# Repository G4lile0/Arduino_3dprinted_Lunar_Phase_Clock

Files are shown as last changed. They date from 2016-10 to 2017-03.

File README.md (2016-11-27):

# Arduino_3dprinted_Lunar_Phase_Clock

<p><a rel="nofollow" href="https://www.youtube.com/watch?v=8Un9RubtGH0">https://www.youtube.com/watch?v=8Un9RubtGH0</a></p>
<h3>3D printed Lunar Phase Clock, designed by G4lile0 2016</h3>
<p><strong>Since there isn't a SuperMoon everyday, make one for your bedside table!!</strong></p>
<p>If you don't know what to print with your 3D printer, here you have an easy project.<br>
Build a 3D printed Lunar Phase Clock for your desk.</p>
<p>Features: (check the video)</p>
<ul>
<li>Open Tools (Ubuntu / FreeCAD / Arduino)</li>
<li>Open Source / Hardware</li>
<li>Cheap HW (Arduino, cheap LCD..) </li>
<li>Only 79 grams of filament.</li>
<li>Precise Lunar Phase Simulation</li>
<li>Detailed 3D printed Lunar model<br>
by Dexter_New_Materials (<a rel="nofollow" href="http://www.thingiverse.com/thing:1014620">http://www.thingiverse.com/thing:1014620</a>)</li>
<li>Alarm  </li>
<li>Wake-light alarm mode</li>
<li>Date </li>
<li>Thermometer</li>
<li>Hygrometer</li>
<li>Lamp mode</li>
<li>Moon FX modes (Relax, Party... )</li>
<li>Bright control</li>
<li>Adjustable tilt</li>
</ul>
<p>Parts List:</p>
<ul>
<li>Arduino compatible Nano (Atmel ATmega328)</li>
<li>0,96'' OLED 128x64 with SSD1306 chip</li>
<li>APA102C led strip  (18 leds)</li>
<li>Tiny RTC (DS1307 real time clock + 24C32 EEPROM)</li>
<li>DTH11 </li>
<li>Buzzer </li>
<li>3 Push Buttons</li>
</ul>
<p><br>
</p>
<h3>Reloj con fase Lunar impreso en 3D diseñado por G4lile0</h3>
<p><strong>Como no todos los días hay una SuperLuna ¡¡fabrícate una para la mesilla de noche!!</strong></p>
<p>Si no sabes que imprimir con tu impresora en 3d, aquí tienes un reloj con fase lunar para tu mesa. </p>
<ul>
<li>Creado solo con herramientas libres (Ubuntu / Freecad / Arduino) </li>
<li>Open Source / Hardware</li>
<li>Electrónica económica (Arduino, LCD)</li>
<li>Tan solo 79 gramos de filamento</li>
<li>Precisa simulacion de la fase lunar</li>
<li>Modelo detallado de la luna<br>
by Dexter_New_Materials (<a rel="nofollow" href="http://www.thingiverse.com/thing:1014620">http://www.thingiverse.com/thing:1014620</a>)</li>
<li>Reloj analogico y digital</li>
<li>Alarma con simulación de amananecer</li>
<li>Alarma</li>
<li>Fecha</li>
<li>Termometro</li>
<li>Monitor de Humedad</li>
<li>Lampara</li>
<li>Modos Demo (Disco /Relax...)</li>
<li>Control de brillo</li>
<li>Inclinación regulable</li>
</ul>
<p>Componentes:</p>
<ul>
<li>Arduino compatible Nano (Atmel ATmega328)</li>
<li>0,96'' OLED 128x64 with SSD1306 chip</li>
<li>APA102C led strip  (18 leds)</li>
<li>Tiny RTC (DS1307 real time clock + 24C32 EEPROM)</li>
<li>DTH11 </li>
<li>Buzzer </li>
<li>3 botones.</li>
</ul>

##Circuito // Circuit
<br>
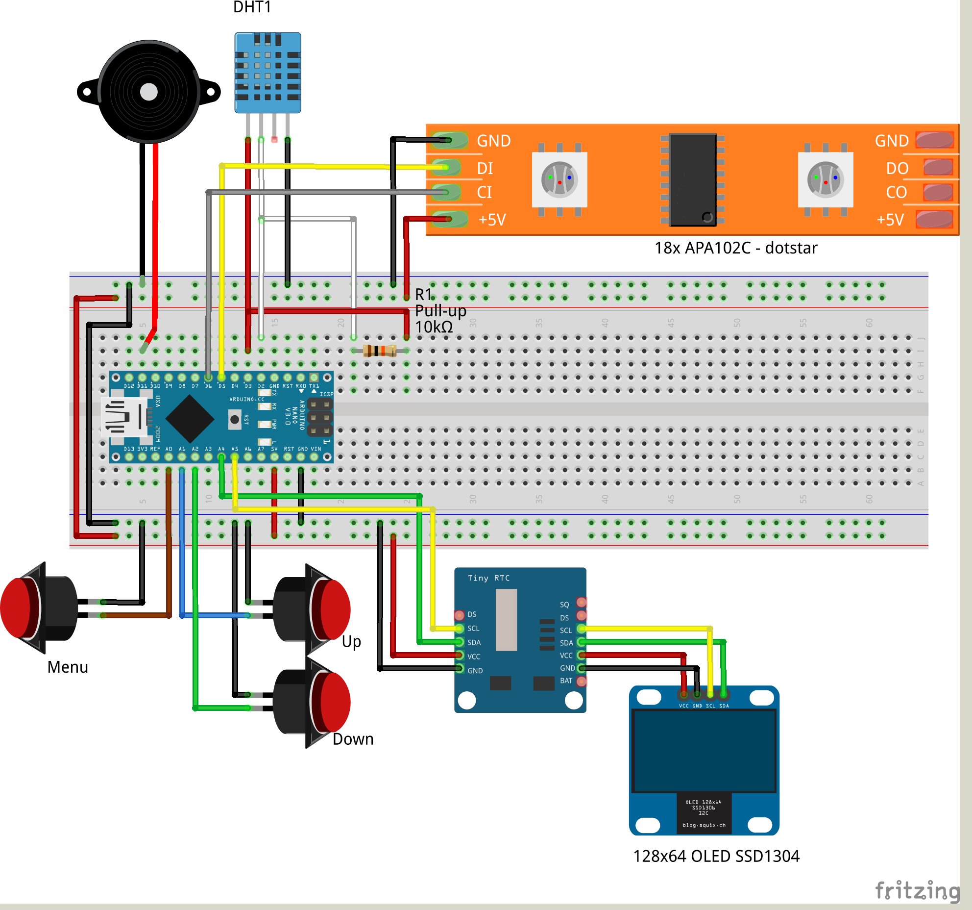
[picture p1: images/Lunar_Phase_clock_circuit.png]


##License



All these products are released under [Creative Commons Attribution-ShareAlike 4.0 International License](http:creativecommons.org/licenses/by-sa/4.0/).
<br>
Todos estos productos están liberados mediante [Creative Commons Attribution-ShareAlike 4.0 International License](http:creativecommons.org/licenses/by-sa/4.0/).

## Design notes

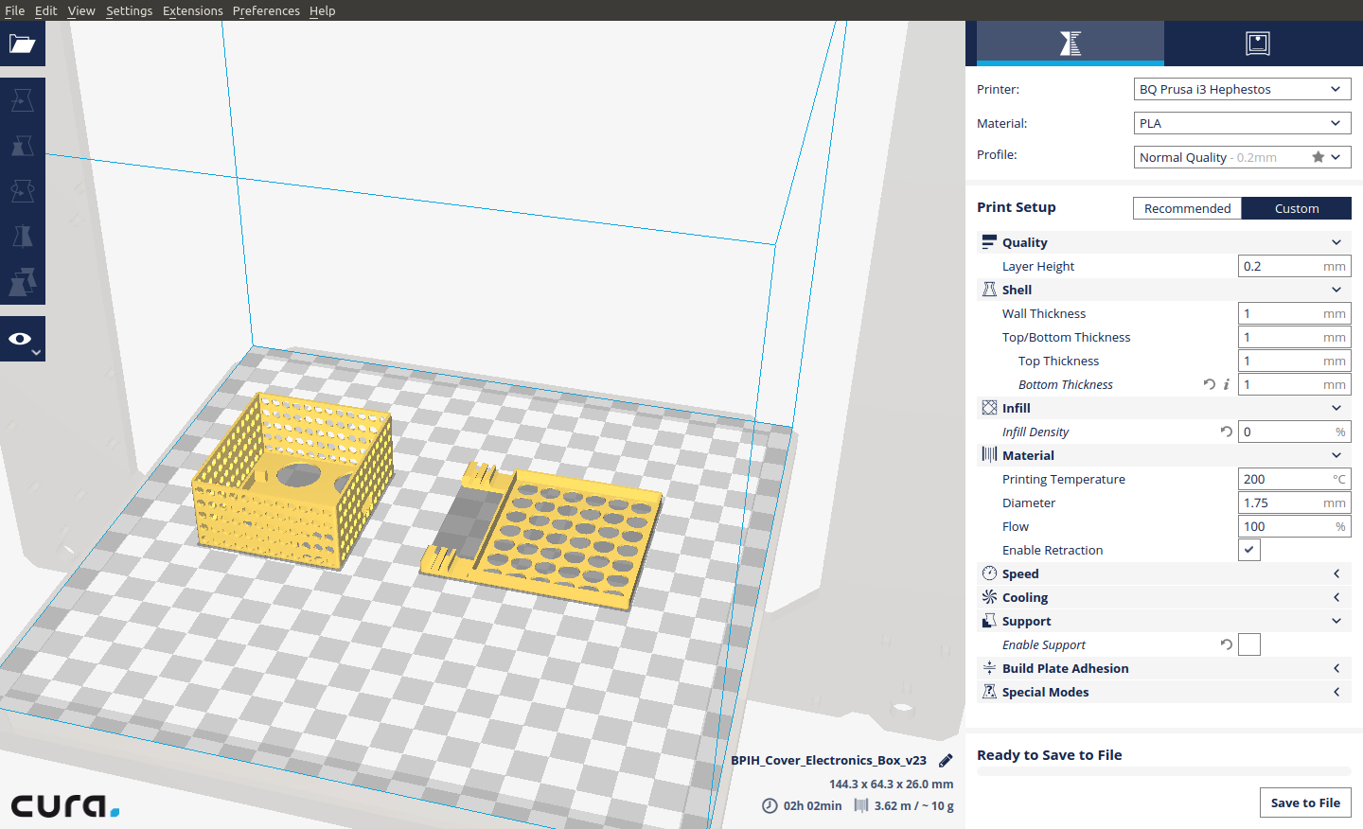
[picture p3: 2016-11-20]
images/electronic_box.png

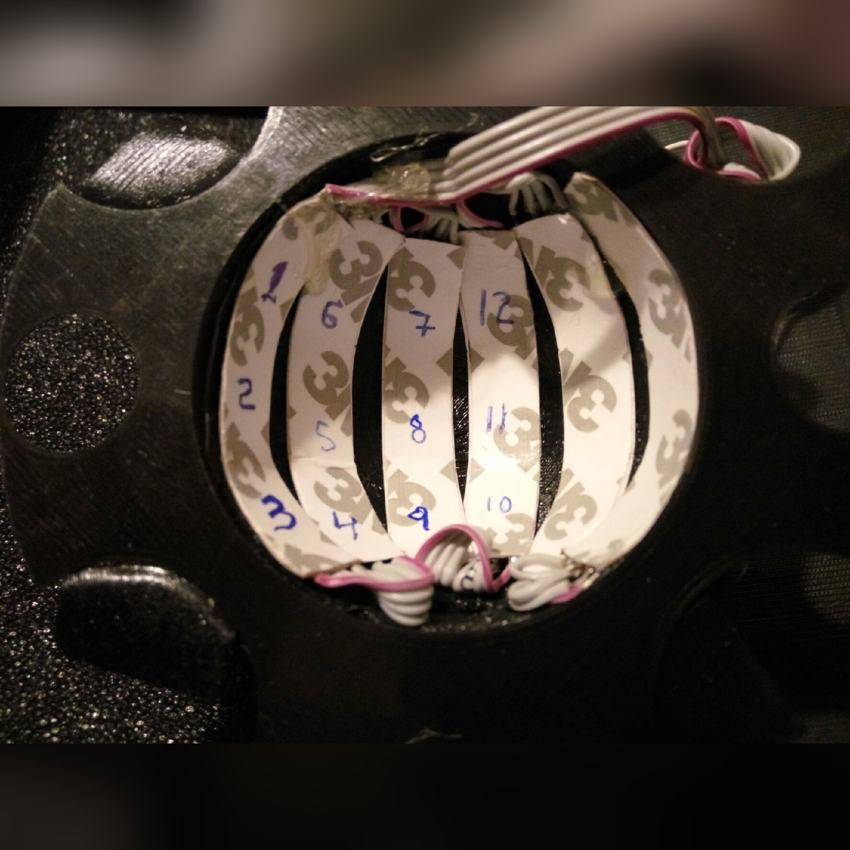
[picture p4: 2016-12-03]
images/led_support_photo.jpg

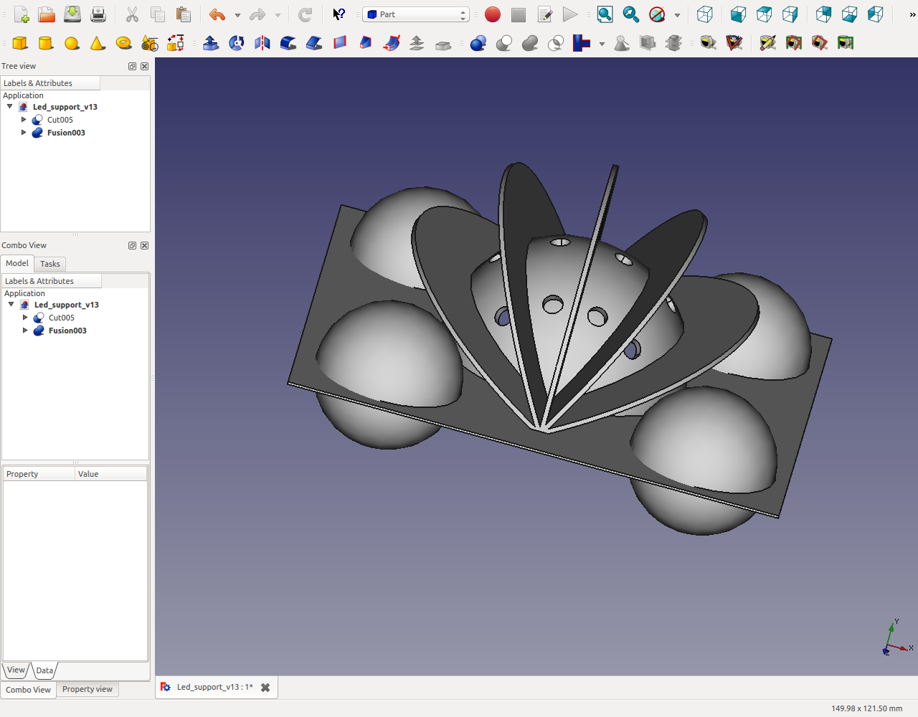
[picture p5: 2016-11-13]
images/Captura de pantalla de 2016-09-18 00-10-19.png

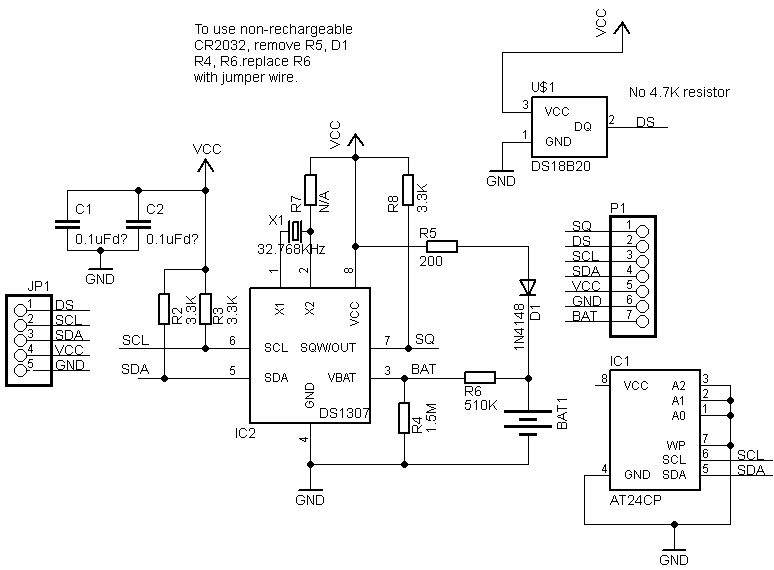
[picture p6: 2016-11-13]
images/TinyRTC.jpg

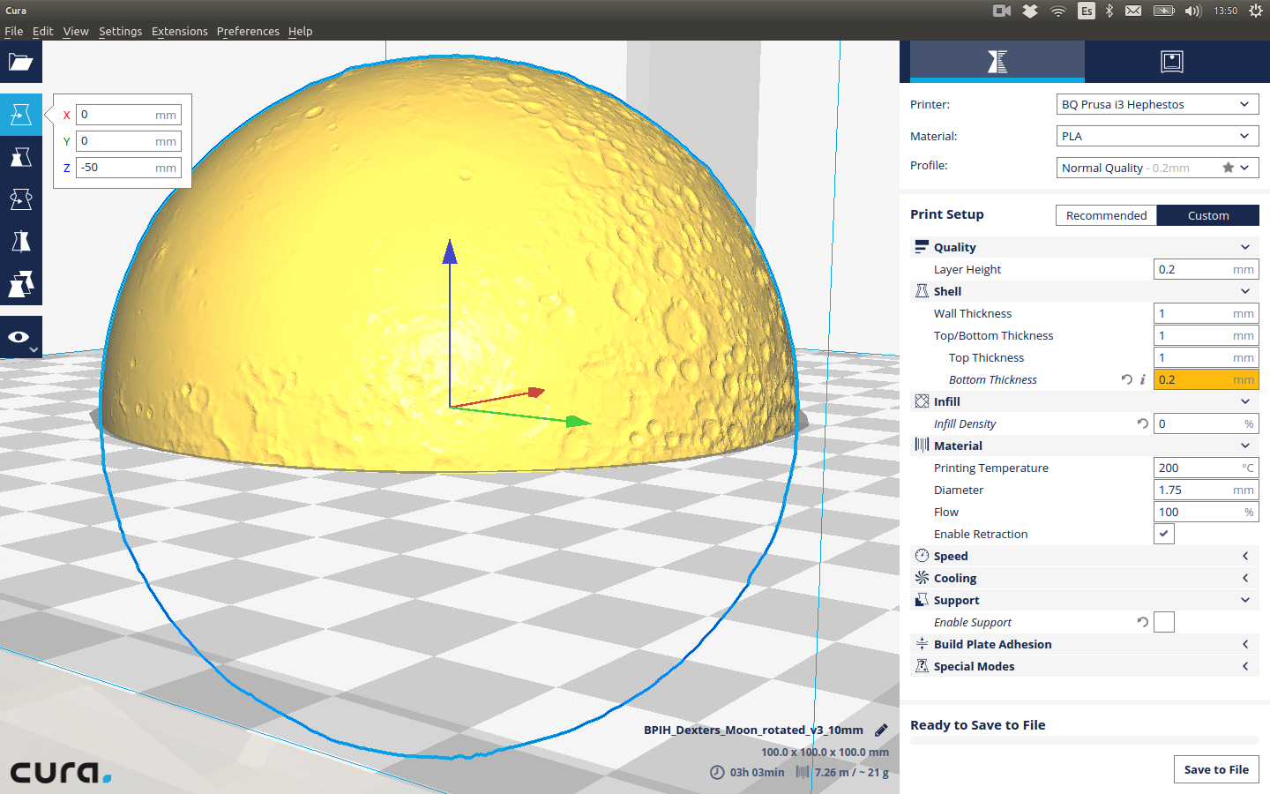
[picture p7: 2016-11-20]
images/cura_moon.png

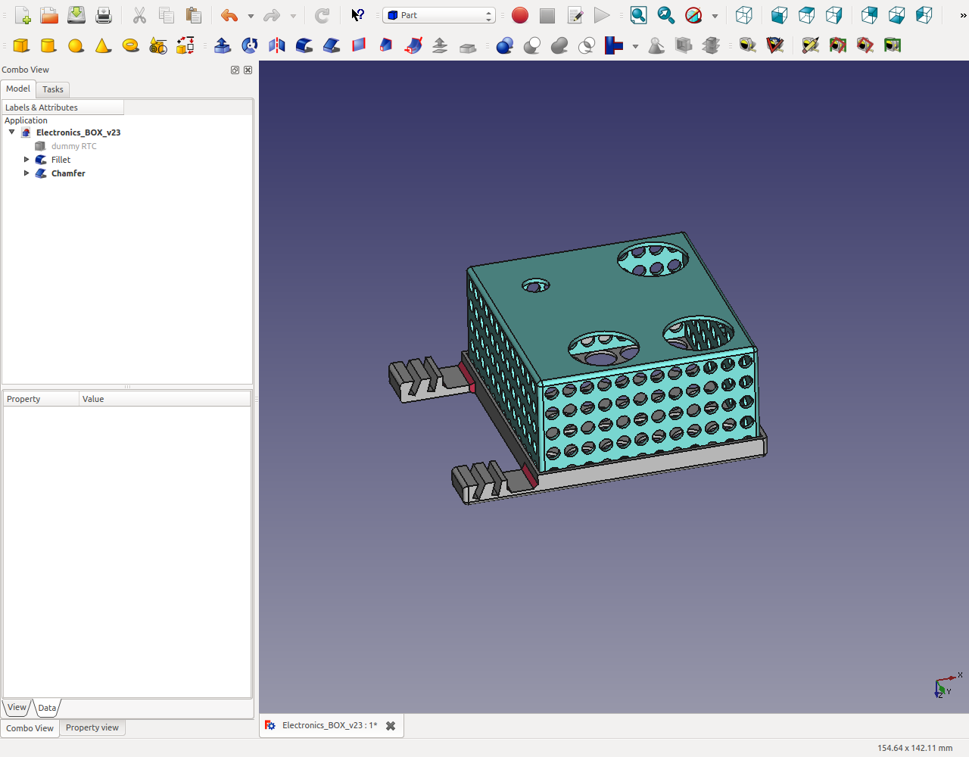
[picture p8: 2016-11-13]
images/Captura de pantalla de 2016-10-10 22-42-48.png

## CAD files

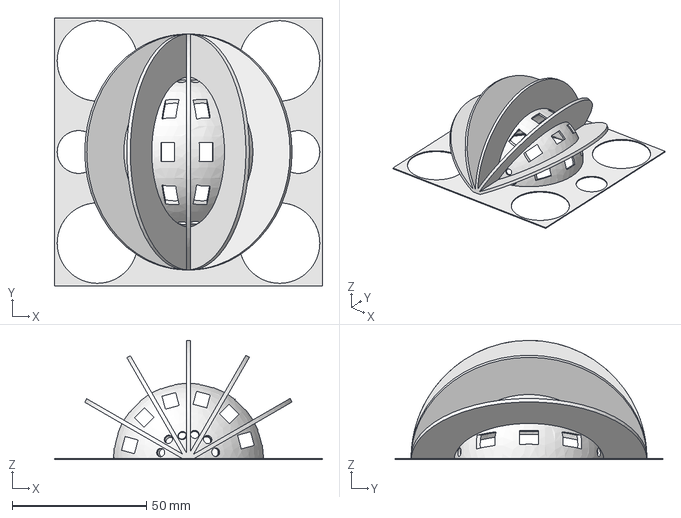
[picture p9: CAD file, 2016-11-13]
parts/freecad/Led_support_v28b_rotated.fcstd
100.0 x 100.0 x 44.5 mm

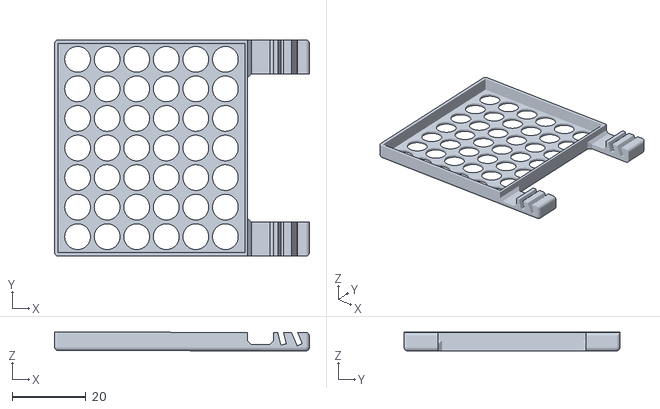
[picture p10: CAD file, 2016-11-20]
parts/stl/Cover_Electronics_Box_v23.stl
69.0 x 58.5 x 5.08

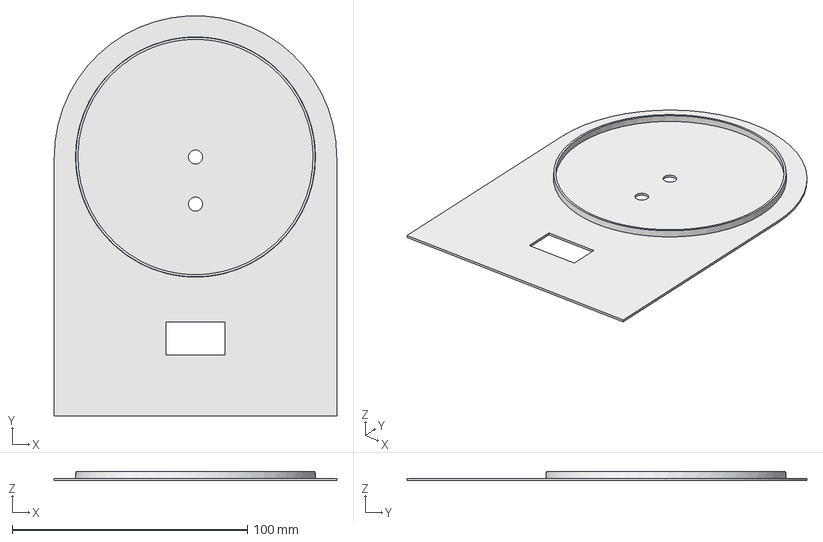
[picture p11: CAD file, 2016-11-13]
parts/freecad/moon_support_v2.fcstd
120.0 x 169.9 x 4.00 mm

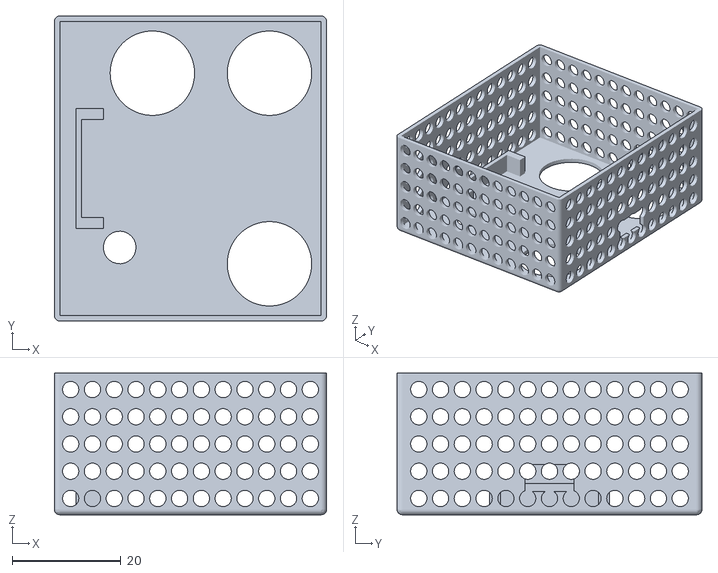
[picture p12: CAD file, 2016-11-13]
parts/stl/Electronics_Box_v21.stl
50.0 x 56.0 x 26.0

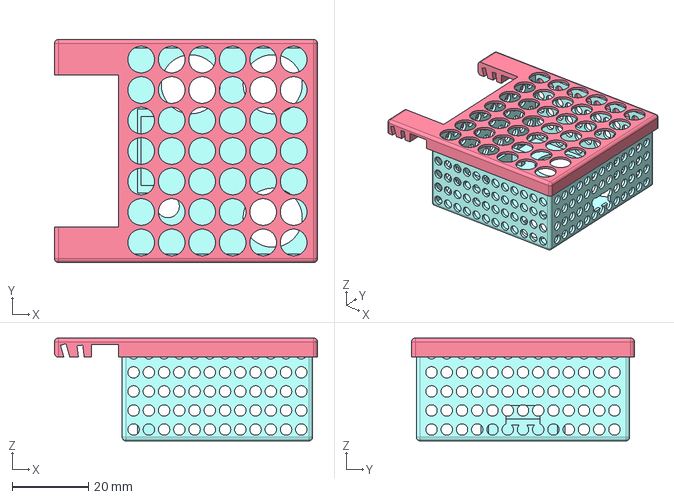
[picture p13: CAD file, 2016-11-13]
parts/freecad/Electronics_BOX_v23.fcstd
69.0 x 58.5 x 27.0 mm

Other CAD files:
parts/stl/moon_support_v21.stl
parts/stl/led_support_v2.8b_rot.stl

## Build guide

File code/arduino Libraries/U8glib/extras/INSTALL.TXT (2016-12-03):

U8GLIB
http://code.google.com/p/u8glib/

Install instructions for the Arduino environment.

  1. Start Arduino IDE
  2. In the Arduino IDE, import the library from the "Add Library" Menu.

Alternative install instructions for the Arduino environment.

  1. Unzip u8glib_arduino_vX.XX.zip into the "libraries" folder of the
      Arduino install directory
  2. Start Arduino IDE

Install instructions for the Chipkit (Arduino) environment.

  1. cd <mpide-... path>/libraries
  2. unzip u8glib_arduino_vX.XX.zip
  3. cd <mpide-... path>///hardware/pic32/libraries
  4. again: u8glib_arduino_vX.XX.zip
  5. Open hardware/pic32/cores/pic32/Print.h
	  Remove line
	    #define BYTE 0
	  from the file, use PRINT_BYTE instead of BYTE.

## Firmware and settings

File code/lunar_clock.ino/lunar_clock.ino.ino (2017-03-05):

/******************************************************************************
Arduino 3D printed Lunar Clock
by G4lile0 


V3.0 13/11/2016
- First public release

V4.0 25/02/2017
- Status is now stored on the RTC NVRAM, this mean that after power failure, clock will return to the old status, moon mode, and alarm configuration instead of load defaul configuration.
NVRAM configuration
00  init_controlA   // if init_contrl_A and B is not 16, NVRAM will load default values
01  init_controlB  // 
02  BRIGHTNESS    // Leds Brightness 
03  beep          // Buttons Beep
04  menu          // menu status
05  moonMode      // Moon Mode
06  alarmHour     // alarm hour
07  alarmMinute   // alarm minute
08  alarmStatus   // Alam status
09  previous moonMode before the alarm.

V4.1  26/02/2017
Added new screen/menu with bigger digital clock.

V4.2  26/02/2017
After an alarm return to the previous status after 1 min.
Fixed bug, when switching the alarm, modify the day of the month :P

V4.2b  5/03/2017
Month changed to double digit format.


OLEd Analog Clock using U8GLIB Library
// Button Long / Short Press script by: 
// (C) 2011 By P. Bauermeister
// http://www.instructables.com/id/Arduino-Dual-Function-Button-Long-PressShort-Press/

// Demo colors moon animations from "FastLED "100-lines-of-code" demo reel" by Mark Kriegsman, December 2014
// Analog clock (first screen) from "OLEd Analog Clock using U8GLIB Library" by Chris Rouse Oct 2014
// moon phase calculations,  algorithm adapted from Stephen R. Schmitt's by  Tim Farley  18 Aug 2009

Note:: Sketch uses 99% of program storage space, 
       Global variables use 56% of dyamic memory, 
       leaving 882 bytes for local variables.

Using a IIC 128x64 OLED with SSD1306 chip
RTC DS1307 
Optional Temperature Sensor TMP 36

Wire RTC:
  VCC +5v
  GND GND
  SDA Analog pin 4
  SCL Analog pin 5
Wire OLED:
  VCC +5v
  GND GND
  SDA Analog pin 4
  SCL Analog pin 5
Wire TMP36:
  VCC +3.3v
  GND GND
  Out Analog pin 1
  


******************************************************************************/

// Add libraries
  #include "U8glib.h"
  #include <SPI.h>
  #include <Wire.h>
  #include "RTClib.h"
  #include "DHT.h"
  #include "FastLED.h"

  // How many leds in your strip?
  #define NUM_LEDS 18
// For led chips like Neopixels, which have a data line, ground, and power, you just
// need to define DATA_PIN.  For led chipsets that are SPI based (four wires - data, clock,
// ground, and power), like the LPD8806 define both DATA_PIN and CLOCK_PIN
#define DATA_PIN 5
#define CLOCK_PIN 6

byte BRIGHTNESS=150;
// Define the array of leds
CRGB leds[NUM_LEDS];

#define FRAMES_PER_SECOND  120

// List of patterns to cycle through.  Each is defined as a separate function below.
typedef void (*SimplePatternList[])();
//SimplePatternList gPatterns = { rainbow, rainbowWithGlitter, confetti, sinelon, juggle, bpm };

uint8_t gCurrentPatternNumber = 0; // Index number of which pattern is current
uint8_t gHue = 0; // rotating "base color" used by many of the patterns



// blinking variables
boolean blinking = true;
unsigned long previousBlinking = 0;  
const long period_Blinking = 500;

// BEEP (to enable o disable buttons BEEPs) 
boolean beep = true;

#define DHTPIN 2     // what digital pin we're connected to

// Uncomment whatever type you're using!
#define DHTTYPE DHT11   // DHT 11
//#define DHTTYPE DHT22   // DHT 22  (AM2302), AM2321
//#define DHTTYPE DHT21   // DHT 21 (AM2301)

// Initialize DHT sensor.
// Note that older versions of this library took an optional third parameter to
// tweak the timings for faster processors.  This parameter is no longer needed
// as the current DHT reading algorithm adjusts itself to work on faster procs.
DHT dht(DHTPIN, DHTTYPE);


// setup u8g object
 // U8GLIB_SSD1306_128X64 u8g(U8G_I2C_OPT_NONE);	// I2C 
  U8GLIB_SH1106_128X64 u8g(U8G_I2C_OPT_NO_ACK);  
//

// Setup RTC
  RTC_DS1307 RTC;
  char monthString[37]= {"JanFebMarAprMayJunJulAugSepOctNovDec"};
  String thisMonth = "";
  String thisTime = "";
  String alarmTime ="";
  String thisDay="";
  byte clockCentreX = 64; // used to fix the centre the analog clock
  byte clockCentreY = 32; // used to fix the centre the analog clock
  

// Menu variables

byte menu = 0;
byte moonMode=0;

//temp
  char buffer[16];

//moonphase variables
int y, m, d, h;


// Alarm Clock
byte alarmHour   = 17; // alarm hour
byte alarmMinute = 04; // alarm minute
boolean alarmStatus = false; 
boolean alarm_button_off = false ; 

// Adapt these to your board and application timings:

#define BUTTON1_PIN              A0  // Button 1     MENU
#define BUTTON2_PIN              A1  // Button 2     UP
#define BUTTON3_PIN              A2  // Button 3     DOWN

#define DEFAULT_LONGPRESS_LEN    10  // Min nr of loops for a long press
#define DELAY                    20  // Delay per loop in ms


//////////////////////////////////////////////////////////////////////////////

enum { EV_NONE=0, EV_SHORTPRESS, EV_LONGPRESS };

//////////////////////////////////////////////////////////////////////////////
// Class definition

class ButtonHandler {
  public:
    // Constructor
    ButtonHandler(int pin, int longpress_len=DEFAULT_LONGPRESS_LEN);

    // Initialization done after construction, to permit static instances
    void init();

    // Handler, to be called in the loop()
    int handle();

  protected:
    boolean was_pressed;     // previous state
    int pressed_counter;     // press running duration
    const int pin;           // pin to which button is connected
    const int longpress_len; // longpress duration
};

ButtonHandler::ButtonHandler(int p, int lp)
: pin(p), longpress_len(lp)    
{
}

void ButtonHandler::init()
{
  pinMode(pin, INPUT);
  digitalWrite(pin, HIGH); // pull-up
  was_pressed = false;
  pressed_counter = 0;
}

int ButtonHandler::handle()
{
  int event;
  int now_pressed = !digitalRead(pin);

  if (!now_pressed && was_pressed) {
    // handle release event
    if (pressed_counter < longpress_len)
      event = EV_SHORTPRESS;
    else
      event = EV_LONGPRESS;
  }
  else
    event = EV_NONE;

  // update press running duration
  if (now_pressed)
    ++pressed_counter;
  else
    pressed_counter = 0;

  // remember state, and we're done
  was_pressed = now_pressed;
  return event;
}

//////////////////////////////////////////////////////////////////////////////

// Instanciate button objects
ButtonHandler button1(BUTTON1_PIN);
ButtonHandler button2(BUTTON2_PIN, DEFAULT_LONGPRESS_LEN*2);
ButtonHandler button3(BUTTON3_PIN);


//void print_event(const char* button_name, int event)
//{
//  if (event)
//  Serial.print(button_name);
//  Serial.print(".SL"[event]);
//  Serial.print(event);
//}



void rainbow() 
{
  // FastLED's built-in rainbow generator
  fill_rainbow( leds, NUM_LEDS, gHue, 7);
}

void rainbowWithGlitter() 
{
  // built-in FastLED rainbow, plus some random sparkly glitter
  rainbow();
  addGlitter(80);
}

void addGlitter( fract8 chanceOfGlitter) 
{
  if( random8() < chanceOfGlitter) {
    leds[ random16(NUM_LEDS) ] += CRGB::White;
  }
}




void menu0(void) {
  // graphic commands to redraw the complete screen should be placed here  
  u8g.setFont(u8g_font_profont15r);
  //u8g.setFont(u8g_font_6x10); 
  //
  //***** RTC **********
  DateTime now = RTC.now();
   // display date at bottom of screen
  
  if (now.day() < 10){ thisDay=" ";} else { thisDay="";}// add leading space if required
  thisDay += String(now.day(), DEC) + "/"; 
  thisMonth="";
  for (int i=0; i<=2; i++){
  thisMonth += monthString[((now.month()-1)*3)+i];
   }  
  thisDay=thisDay + thisMonth + "/"; 
  thisDay=thisDay + String(now.year() , DEC);
  const char* newDay = (const char*) thisDay.c_str(); 
  u8g.drawStr(22,63, newDay);   

  // ********************* 
  // display time in digital format
  thisTime="";
  if (now.hour() < 10){ thisTime=thisTime + " ";} // add leading space if required
  thisTime=String(now.hour()) + ":";
  if (now.minute() < 10){ thisTime=thisTime + "0";} // add leading zero if required
  thisTime=thisTime + String(now.minute()) + ":";
  if (now.second() < 10){ thisTime=thisTime + "0";} // add leading zero if required
  thisTime=thisTime + String(now.second());
  const char* newTime = (const char*) thisTime.c_str();
  
  u8g.drawStr(10,10, newTime);  
  // ********************* 
  //
  // Now draw the clock face
  u8g.drawCircle(clockCentreX, clockCentreY, 20); // main outer circle
  u8g.drawCircle(clockCentreX, clockCentreY, 2);  // small inner circle
  //
  //hour ticks
  for( int z=0; z < 360;z= z + 30 ){
  //Begin at 0° and stop at 360°
    float angle = z ;
    angle=(angle/57.29577951) ; //Convert degrees to radians
    int x2=(clockCentreX+(sin(angle)*20));
    int y2=(clockCentreY-(cos(angle)*20));
    int x3=(clockCentreX+(sin(angle)*(20-5)));
    int y3=(clockCentreY-(cos(angle)*(20-5)));
    u8g.drawLine(x2,y2,x3,y3);
  }
  // display second hand
  float angle = now.second()*6 ;
  angle=(angle/57.29577951) ; //Convert degrees to radians  
  int x3=(clockCentreX+(sin(angle)*(20)));
  int y3=(clockCentreY-(cos(angle)*(20)));
  u8g.drawLine(clockCentreX,clockCentreY,x3,y3);
  //
  // display minute hand
  angle = now.minute() * 6 ;
  angle=(angle/57.29577951) ; //Convert degrees to radians  
  x3=(clockCentreX+(sin(angle)*(20-3)));
  y3=(clockCentreY-(cos(angle)*(20-3)));
  u8g.drawLine(clockCentreX,clockCentreY,x3,y3);
  //
  // display hour hand
  angle = now.hour() * 30 + int((now.minute() / 12) * 6 )   ;
  angle=(angle/57.29577951) ; //Convert degrees to radians  
  x3=(clockCentreX+(sin(angle)*(20-11)));
  y3=(clockCentreY-(cos(angle)*(20-11)));
  u8g.drawLine(clockCentreX,clockCentreY,x3,y3);
 //
 // now add temperature if needed
 //getting the voltage reading from the temperature sensor
  // tempReading = analogRead(tempPin);   
 // converting that reading to voltage, for 3.3v arduino use 3.3
  // float voltage = tempReading * aref_voltage;
//   voltage /= 1024.0; 
 // now print out the temperature
 //  int temperatureC = (voltage - 0.5) * 100 ;  //converting from 10 mv per degree wit 500 mV offset
   //float t = dht.readTemperature();

  //
   //char Tstr[5];
   //dtostrf(dht.readTemperature(), 3,0, Tstr);
   //String thisTemp1 = String(abs(dht.readTemperature())) + "C";
   String thisTemp1 = String((int) dht.readTemperature()) + "C";
      // printing output as follows used less program storage space
   const char* thisTemp = (const char*) thisTemp1.c_str();
   u8g.drawStr(90,10,thisTemp); 
   // the print command could be used, but uses more memory
   //u8g.setPrintPos(100,10); thisMonth="";
  for (int i=0; i<=2; i++){
  thisMonth += monthString[((now.month()-1)*3)+i];
   }  
 
   //u8g.print(thisTemp1);

//
//
}




void menu1(void) {
   //***** RTC **********
  DateTime now = RTC.now();
  // ********************* 
  // display time in digital format
  u8g.setFont(u8g_font_osb21n); 
//  thisTime="";
//  if (now.hour() < 10){ thisTime=thisTime + " ";} // add leading space if required
  thisTime=String(now.hour()) + ":";
  if (now.minute() < 10){ thisTime=thisTime + "0";} // add leading zero if required
  thisTime=thisTime + String(now.minute()) + ":";
  if (now.second() < 10){ thisTime=thisTime + "0";} // add leading zero if required
  thisTime=thisTime + String(now.second());
  const char* newTime = (const char*) thisTime.c_str();
  if (now.hour()  < 10){ u8g.drawStr(21,30, newTime);} else {u8g.drawStr(5,30, newTime);} // add leading space if required

  u8g.setFont(u8g_font_profont15r);
  alarmTime="";
  if (alarmHour < 10){ alarmTime="0";} // add leading zero if required
  alarmTime=alarmTime + String (alarmHour)+":";
  if (alarmMinute < 10){ alarmTime=alarmTime+ "0";} // add leading zero if required
  alarmTime=alarmTime + String(alarmMinute);
  if (alarmStatus == 0) { alarmTime=alarmTime + " Off" ;} else { alarmTime=alarmTime + " On" ;}
  const char* newalarmTime = (const char*) alarmTime.c_str(); 
  u8g.drawStr(35,50, newalarmTime);

}


void menu11(void) {
menu1();
if (blinking) u8g.drawFrame(4, 4, 35, 30);
}

void menu12(void) {
menu1();
if (blinking) u8g.drawFrame(43, 4, 35, 30) ;
}

void menu13(void) {
menu1();
if (blinking) u8g.drawFrame(84, 4, 35, 30) ;

}


void menu14(void) {
menu1();
if (blinking) u8g.drawFrame(33, 38, 17, 16) ;

}
void menu15(void) {
menu1();
if (blinking) u8g.drawFrame(54, 38, 17, 16) ;

}
void menu16(void) {
menu1();
if (blinking) u8g.drawFrame(74, 38, 24, 16) ;

}




void menu3(void) {
  // graphic commands to redraw the complete screen should be placed here  
  // u8g.setFont(u8g_font_profont22);  
  u8g.setFont(u8g_font_osb21n); 
  //
  //***** RTC **********
  DateTime now = RTC.now();
   // display date at bottom of screen
  if (now.day() < 10){ thisDay="_";} // add leading space if required
  thisDay = String(now.day(), DEC) + "/"; 
  // thisDay=thisDay + thisMonth + "/"; 

  if (now.month() < 10){ thisDay=thisDay+ "0";} // add leading space if required

  
  thisDay=thisDay + String(now.month() , DEC);

  thisDay=thisDay + thisMonth + "/"; 
// to add only the 3rd and the 4th digit.. other option is to subtract 2000
  thisDay=thisDay + String((now.year()-2000) , DEC);

// thisDay=thisDay + String(now.year()%10 + '0' , DEC);
// thisDay=thisDay + String((now.year()/10)%10 + '0', DEC);
   
  const char* newDay = (const char*) thisDay.c_str(); 
  if (now.day() < 10){ u8g.drawStr(18,35, newDay);} else {u8g.drawStr(2,35, newDay);} // add leading space if required
}


void menu31(void) {
menu3();
if (blinking) u8g.drawFrame(1, 10, 35, 29) ;

}

void menu32(void) {
menu3();
if (blinking) u8g.drawFrame(45, 10, 35, 29) ;

}

void menu33(void) {
menu3();
if (blinking) u8g.drawFrame(91, 10, 35, 29) ;

}



void menu2(void) {
    u8g.setFont(u8g_font_osb21n); 
    u8g.setScale2x2();  
   //char Tstr[5];
   //dtostrf(dht.readTemperature(), 3,0, Tstr);
   //String thisTemp1 = String(abs(dht.readTemperature())) + "C";
   String thisTemp1 = String((int) dht.readTemperature());
      // printing output as follows used less program storage space
   const char* thisTemp = (const char*) thisTemp1.c_str();
   u8g.drawStr(13,28,thisTemp); 
  u8g.setFont(u8g_font_profont15r);
  u8g.drawStr(45,13,"o"); 
  u8g.undoScale(); 
//  tone (11,2000,500);
  
}               


void menu4(void) {
    u8g.setFont(u8g_font_osb21n); 
    u8g.setScale2x2();  
   //char Tstr[5];
   //dtostrf(dht.readTemperature(), 3,0, Tstr);
   //String thisTemp1 = String(abs(dht.readTemperature())) + "C";
   String thisTemp1 = String((int) dht.readHumidity());
      // printing output as follows used less program storage space
   const char* thisTemp = (const char*) thisTemp1.c_str();
   u8g.drawStr(13,28,thisTemp); 
  u8g.setFont(u8g_font_profont15r);
  u8g.drawStr(46,24,"%"); 
  u8g.undoScale(); 
 
}               


void menu5(void) {

char buf[4];
u8g.drawStr( 0, 15, "Config Menu:");
u8g.drawStr( 0, 33, "Bright:");  // de 34 a 33
snprintf (buf, 4, "%d", BRIGHTNESS);
u8g.drawStr(80, 33, buf);  //de 90 a 80
u8g.drawStr( 0, 48, "Beep:");    
if (beep) { u8g.drawStr(80, 49, "On");} else { u8g.drawStr(80, 48, "Off"); }
u8g.drawStr( 0, 63, "Moon mode:");
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
void loop(void) {


 // blinking timer for the setup selector

unsigned long currentMillis = millis();

  if (currentMillis - previousBlinking >= period_Blinking ) {
    // save the last time you blinked
    previousBlinking = currentMillis;
    blinking=!blinking;
  }
   

  
  // picture loop
  u8g.firstPage();  
  do {

             switch (menu)
               {  case 0:                       
                     menu0();
                     break;  
                  case 1:                       
                     menu1();
                     break;  
                  case 11:                       
                     menu11();
                     break;  
                  case 12:                       
                     menu12();
                     break;
                  case 13:                       
                     menu13();
                     break;
                  case 14:                       
                     menu14();
                     break;
                  case 15:                       
                     menu15();
                     break;
                  case 16:                       
                     menu16();
                     break;

                     
                  case 2:                       
                     menu2();
                     break;  

                  case 31:                       
                     menu31();
                     break;  
                  case 32:                       
                     menu32();
                     break;
                  case 33:                       
                     menu33();
                     break;
                  case 3:                       
                     menu3();
                     break;
                  case 4:                       
                     menu4();
                     break;
                     
                  case 5:                       
                     menu5();
                     break;

                  case 51:                       
                     menu51();
                     break;  
                  case 52:                       
                     menu52();
                     break;
                  case 53:                       
                     menu53();
                     break;               

                case 6:                       
                     menu6();
                     break;

               
               }

  
  } while( u8g.nextPage() );

  
  // rebuild the picture after some delay
//   delay(50);

   // handle button
  int event1 = button1.handle();
  int event2 = button2.handle();
  int event3 = button3.handle();
  

  // do other things
//  print_event("1 eve %d", event1);
//  print_event("2 eve %d" ,event2);
//  print_event("3 eve %d" ,event3);
//
//    sprintf(buffer, "Menu is %d", menu);
//    Serial.println(buffer);


//   sprintf(buffer, "Alarma %d", alarm_button_off);
//    Serial.println(buffer);

 
 // Action of the Long Press on Button 1 within each Menu.
   if (event1 == 2)
          { if (beep) tone (11,2000,40);             
             switch (menu)
               {
                  case 1:                       
                     menu=11;
                     break;  
                  case 3:                       
                     menu=31;
                     break;
                  case 5:                       
                     menu=51;
                     break;
                       
               }
         }

DateTime now = RTC.now();

 // Action of the Short Press on Button 2 within each Menu.
   if (event2 == 1)
          { if (beep) tone (11,3000,60);
             switch (menu)
               {
                  case 11:
                   RTC.adjust(DateTime( now.year(), now.month(),  now.day(), (now.hour()+1)%24, now.minute(), now.second()));
                   break;  
                  case 12:                       
                   RTC.adjust(DateTime( now.year(), now.month(),  now.day(), now.hour(), (now.minute()+1)%60, now.second()));
                    break;  
                  case 13:                       
                   RTC.adjust(DateTime( now.year(), now.month(),  now.day(), now.hour(), now.minute(), now.second()+1));
                   break;  

                  case 14:
                  alarmHour=alarmHour+1;
                   break;
                  case 15:
                  alarmMinute=alarmMinute+1;
                   break;
                  case 16:
                  alarmStatus=!alarmStatus;
                  break;

                  case 31:
                   RTC.adjust(DateTime( now.year(), now.month(),  (now.day()+1)%32, now.hour(), now.minute(), now.second()));
                   break;  
                  case 32:                       
                   RTC.adjust(DateTime( now.year(), (now.month()+1) %13,  now.day(), now.hour(), now.minute(), now.second()));
                    break;  
                  case 33:                       
                   RTC.adjust(DateTime( now.year()+1, now.month(),  now.day(), now.hour(), now.minute(), now.second()));
                   break;  

                  case 51:
                  BRIGHTNESS=BRIGHTNESS+10;
                  FastLED.setBrightness(BRIGHTNESS);
                  break;

                  case 52:
                  beep=!beep;
                  break;

                  case 53:
                  moonMode=(moonMode+1)% 9;
                  break;
               
               }
         }




// we store the status of the Moon, prior to run the alarm
if ((now.hour()==alarmHour) && (now.minute()== alarmMinute) && (now.second()==0)) {
   RTC.writenvram(9,moonMode);
   delay(1000); // to avoid to run this code two times.
      }

if ((alarmStatus) && (!alarm_button_off)) {

  
  if ((now.hour()==alarmHour) && (now.minute()== alarmMinute)) {
     
      moonMode=7;
      if (blinking) tone (11,6000,60);
            
      if ((event1 ==1) or (event2 ==1) or (event3 == 1)) { 
        alarm_button_off= true;
        moonMode = RTC.readnvram(9);
      }
          }
  }
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

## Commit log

2016-11-13 carga de codigo y piezas
    [Cover_Electronics_Box_v23.stl, Electronics_BOX_v23.fcstd, Electronics_Box_v21.stl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]
2016-11-20 Delete Captura de pantalla de 2016-09-18 01-35-32.png
    No need for support
2016-11-20 añadidas fotos
    [Cover_Electronics_Box_v23.stl]
2016-11-27 added circuit
2016-12-21 added litle version without support of the DTH sensor
2017-03-05 test de commit con email
